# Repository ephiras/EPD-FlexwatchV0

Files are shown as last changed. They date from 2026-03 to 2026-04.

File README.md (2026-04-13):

# The Inkwell Watch (A curved eink watch)

previously the flexwatch.

A simple, low stress smartwatch built around a 2.9 inch e ink display, a custom PCB, and a lot of improvised problem solving. This repository contains the Arduino code and the Eagle hardware files for the current working version.

The goal is a comfortable watch that is easy on the eyes, lasts a long time on a charge, and does not behave like a tiny phone.


---

## What is in this repository

### code
Arduino sketches for the current version.  
Bluetooth and microphone support are not implemented yet, but the hardware is ready.

### hardware
Eagle schematic and PCB layout for the custom flex board used in the build.
tmp_00848f6a-d5dd-4d53-946b-520c7fa0a136
---

## Current features

- 2.9 inch e ink display  
- Seeed Studio nRF52840 Sense  
- IMU support  
- Basic watch interface  
- Low power modes  
- Custom flex PCB  
- Ruler based rigid frame  

---

## Planned features

- Bluetooth  
- Microphone  
- GPS (new layout needed)  
- Heart rate sensor  
- UV sensor  
- Rigid flex PCB  
- Improved sleep modes  
- RTC backup battery  

---

# The Zephyr Migration
I’ve started migrating the firmware for the e‑ink smartwatch from the Arduino environment to Zephyr RTOS. This is a significant step forward for the project and sets up a much more robust foundation for future development.

## Why the migration
- Better power management: Zephyr gives fine‑grained control over sleep states, peripherals, and scheduling, which is essential for a low‑power wearable running on a small battery.
- Native nRF52840 support: Zephyr’s Nordic integration is far deeper than Arduino’s, with first‑class drivers, BLE stack support, and stable APIs.
- Modular architecture: The RTOS structure makes it easier to separate display handling, sensors, BLE, and UI logic into clean, maintainable modules.
- Scalability: As the watch grows beyond a simple prototype, Arduino’s abstractions become limiting. Zephyr provides a long‑term path for more complex features.

---

## Notes
This is a work in progress.  
The hardware files match the version shown in the Instructables build.  https://www.instructables.com/Building-a-Lightweight-Curved-EInk-Smartwatch/
Expect changes as the design evolves.

if you want to, please join the discord
https://discord.gg/58VtJPHzf

## License

MIT License.  
Feel free to use, modify, and build on this project.

Please reach out or credit me if you do use any of my schematics/ pcb layout. I would really appreciate it! would also be great to see what you come up with.

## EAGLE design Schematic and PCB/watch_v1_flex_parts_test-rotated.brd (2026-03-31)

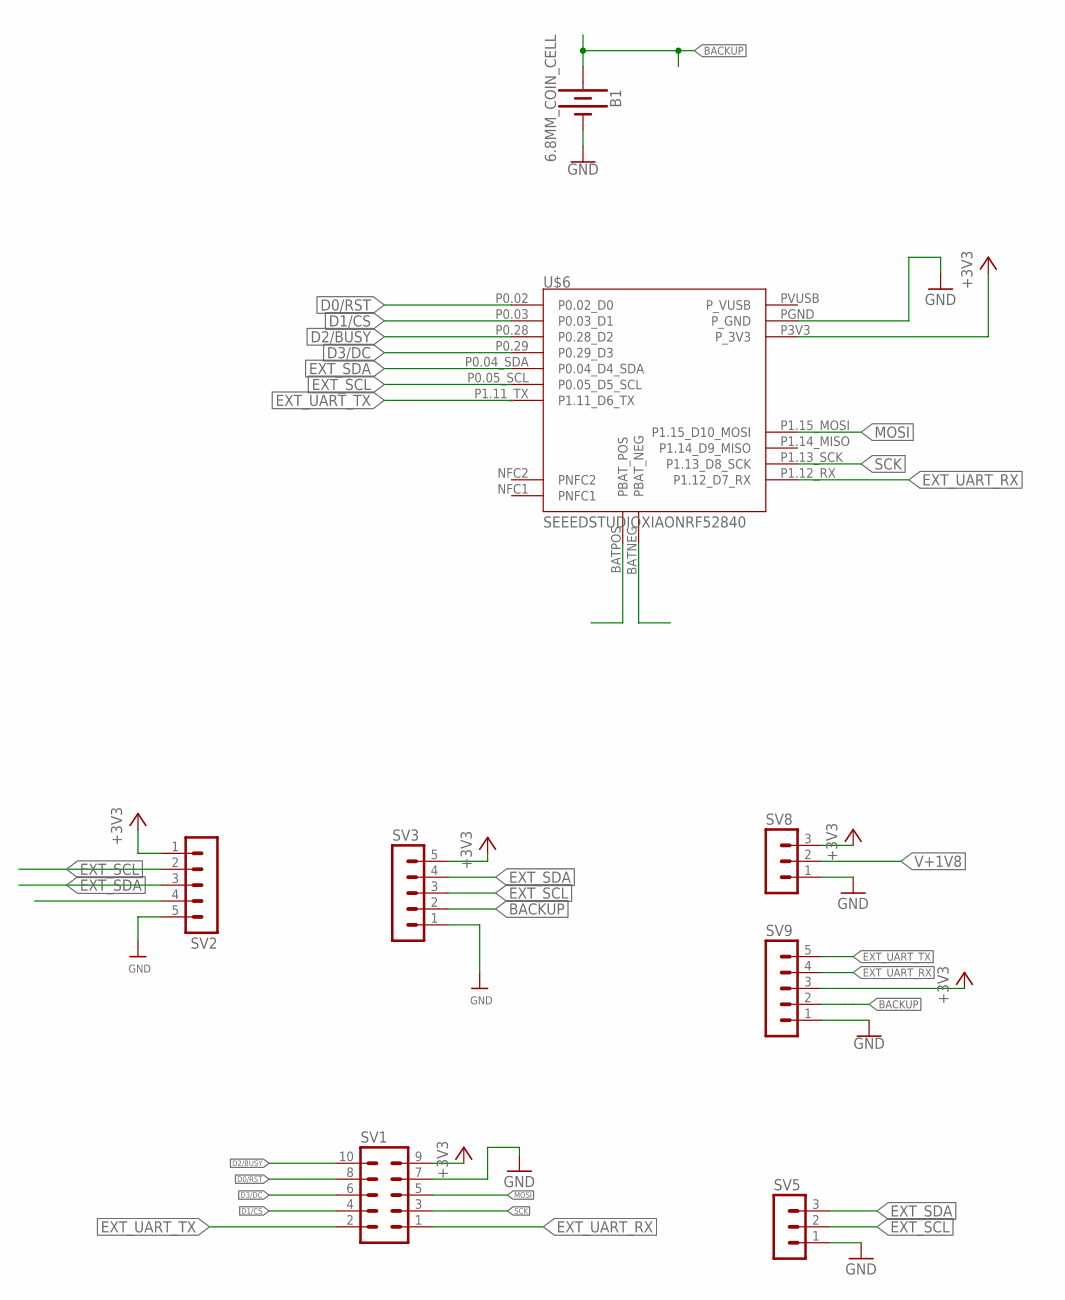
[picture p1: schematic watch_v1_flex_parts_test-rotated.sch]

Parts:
B1: 6.8MM_COIN_CELL; ML414H_IV01E
SV1: MA05-2
SV2, SV3, SV9: MA05-1
SV5, SV8: MA03-1
U$6: SEEEDSTUDIOXIAONRF52840

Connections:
+3V3: SV1.9, SV2.1, SV3.5, SV8.3, SV9.3, U$6.P3V3 (P_3V3)
BACKUP: B1.+, SV3.2, SV9.2
D0/RST: SV1.8, U$6.P0.02 (P0.02_D0)
D1/CS: SV1.4, U$6.P0.03 (P0.03_D1)
D2/BUSY: SV1.10, U$6.P0.28 (P0.28_D2)
D3/DC: SV1.6, U$6.P0.29 (P0.29_D3)
EXT_SCL: SV2.2, SV3.3, SV5.2, U$6.P0.05_SCL (P0.05_D5_SCL)
EXT_SDA: SV2.3, SV3.4, SV5.3, U$6.P0.04_SDA (P0.04_D4_SDA)
EXT_UART_RX: SV1.1, SV9.4, U$6.P1.12_RX (P1.12_D7_RX)
EXT_UART_TX: SV1.2, SV9.5, U$6.P1.11_TX (P1.11_D6_TX)
GND: B1.-, SV1.7, SV2.5, SV3.1, SV5.1, SV8.1, SV9.1, U$6.PGND (P_GND)
MOSI: SV1.5, U$6.P1.15_MOSI (P1.15_D10_MOSI)
SCK: SV1.3, U$6.P1.13_SCK (P1.13_D8_SCK)
V+1V8: SV8.2

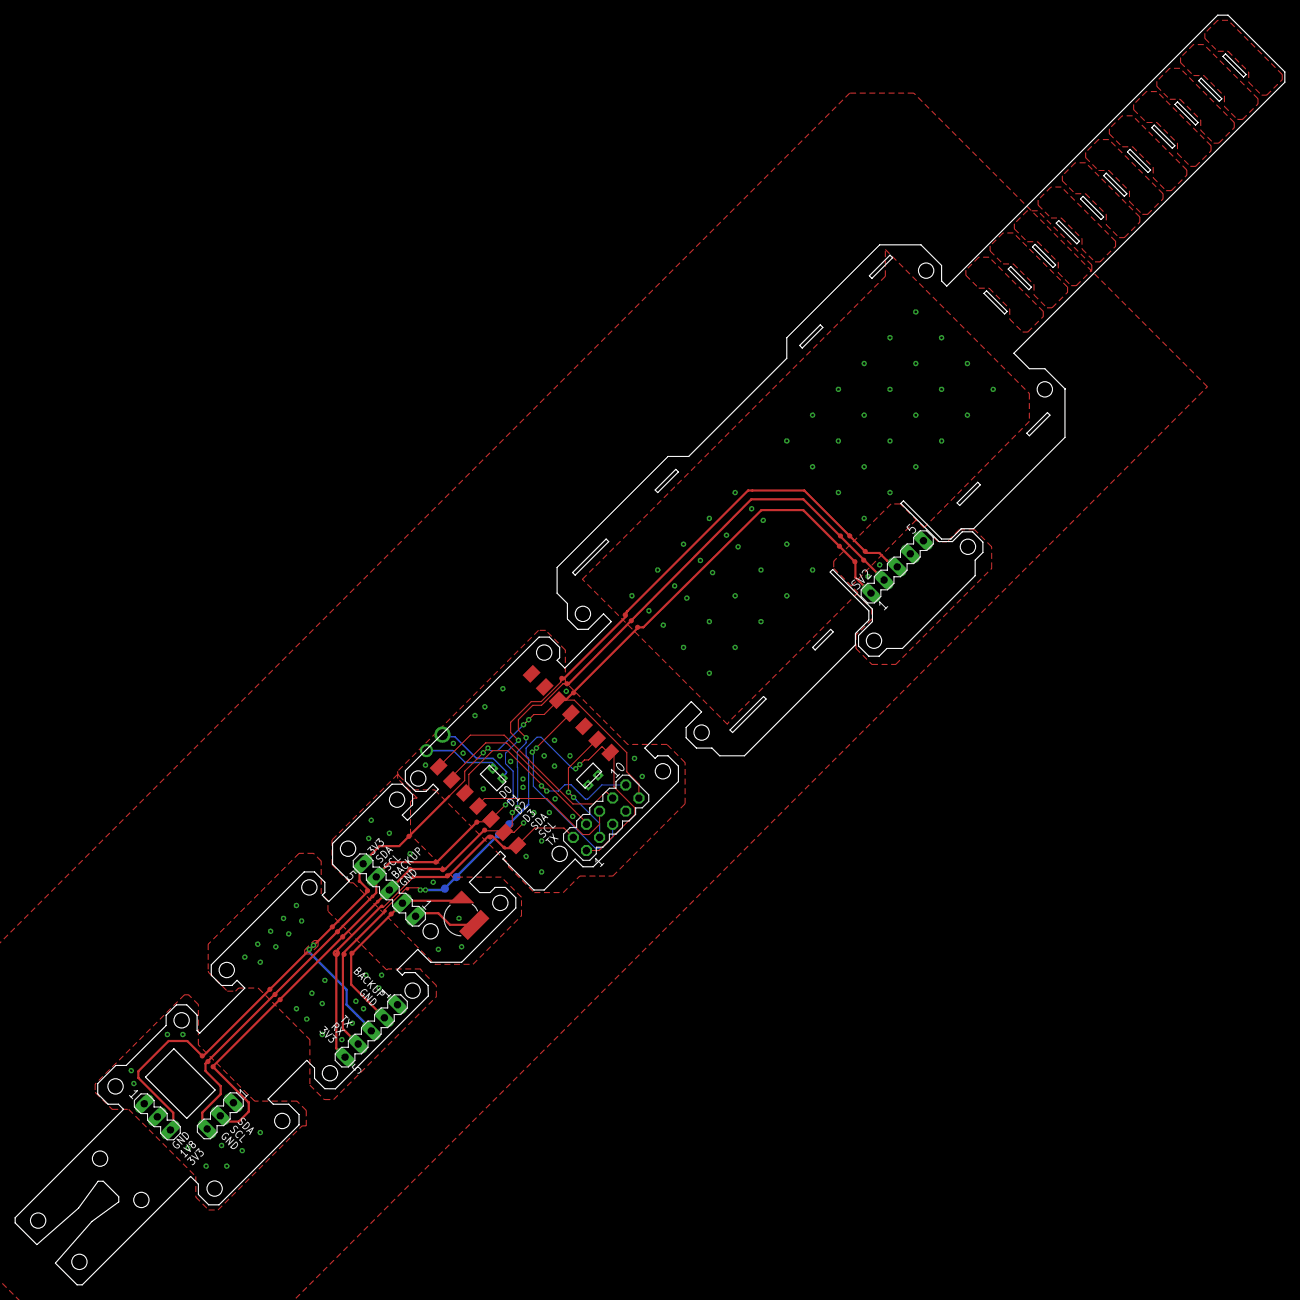
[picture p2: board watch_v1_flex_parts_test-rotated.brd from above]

Board: 2 copper layers, 173.9 x 173.9 mm, 8 parts (0 on the bottom side), 13 nets.

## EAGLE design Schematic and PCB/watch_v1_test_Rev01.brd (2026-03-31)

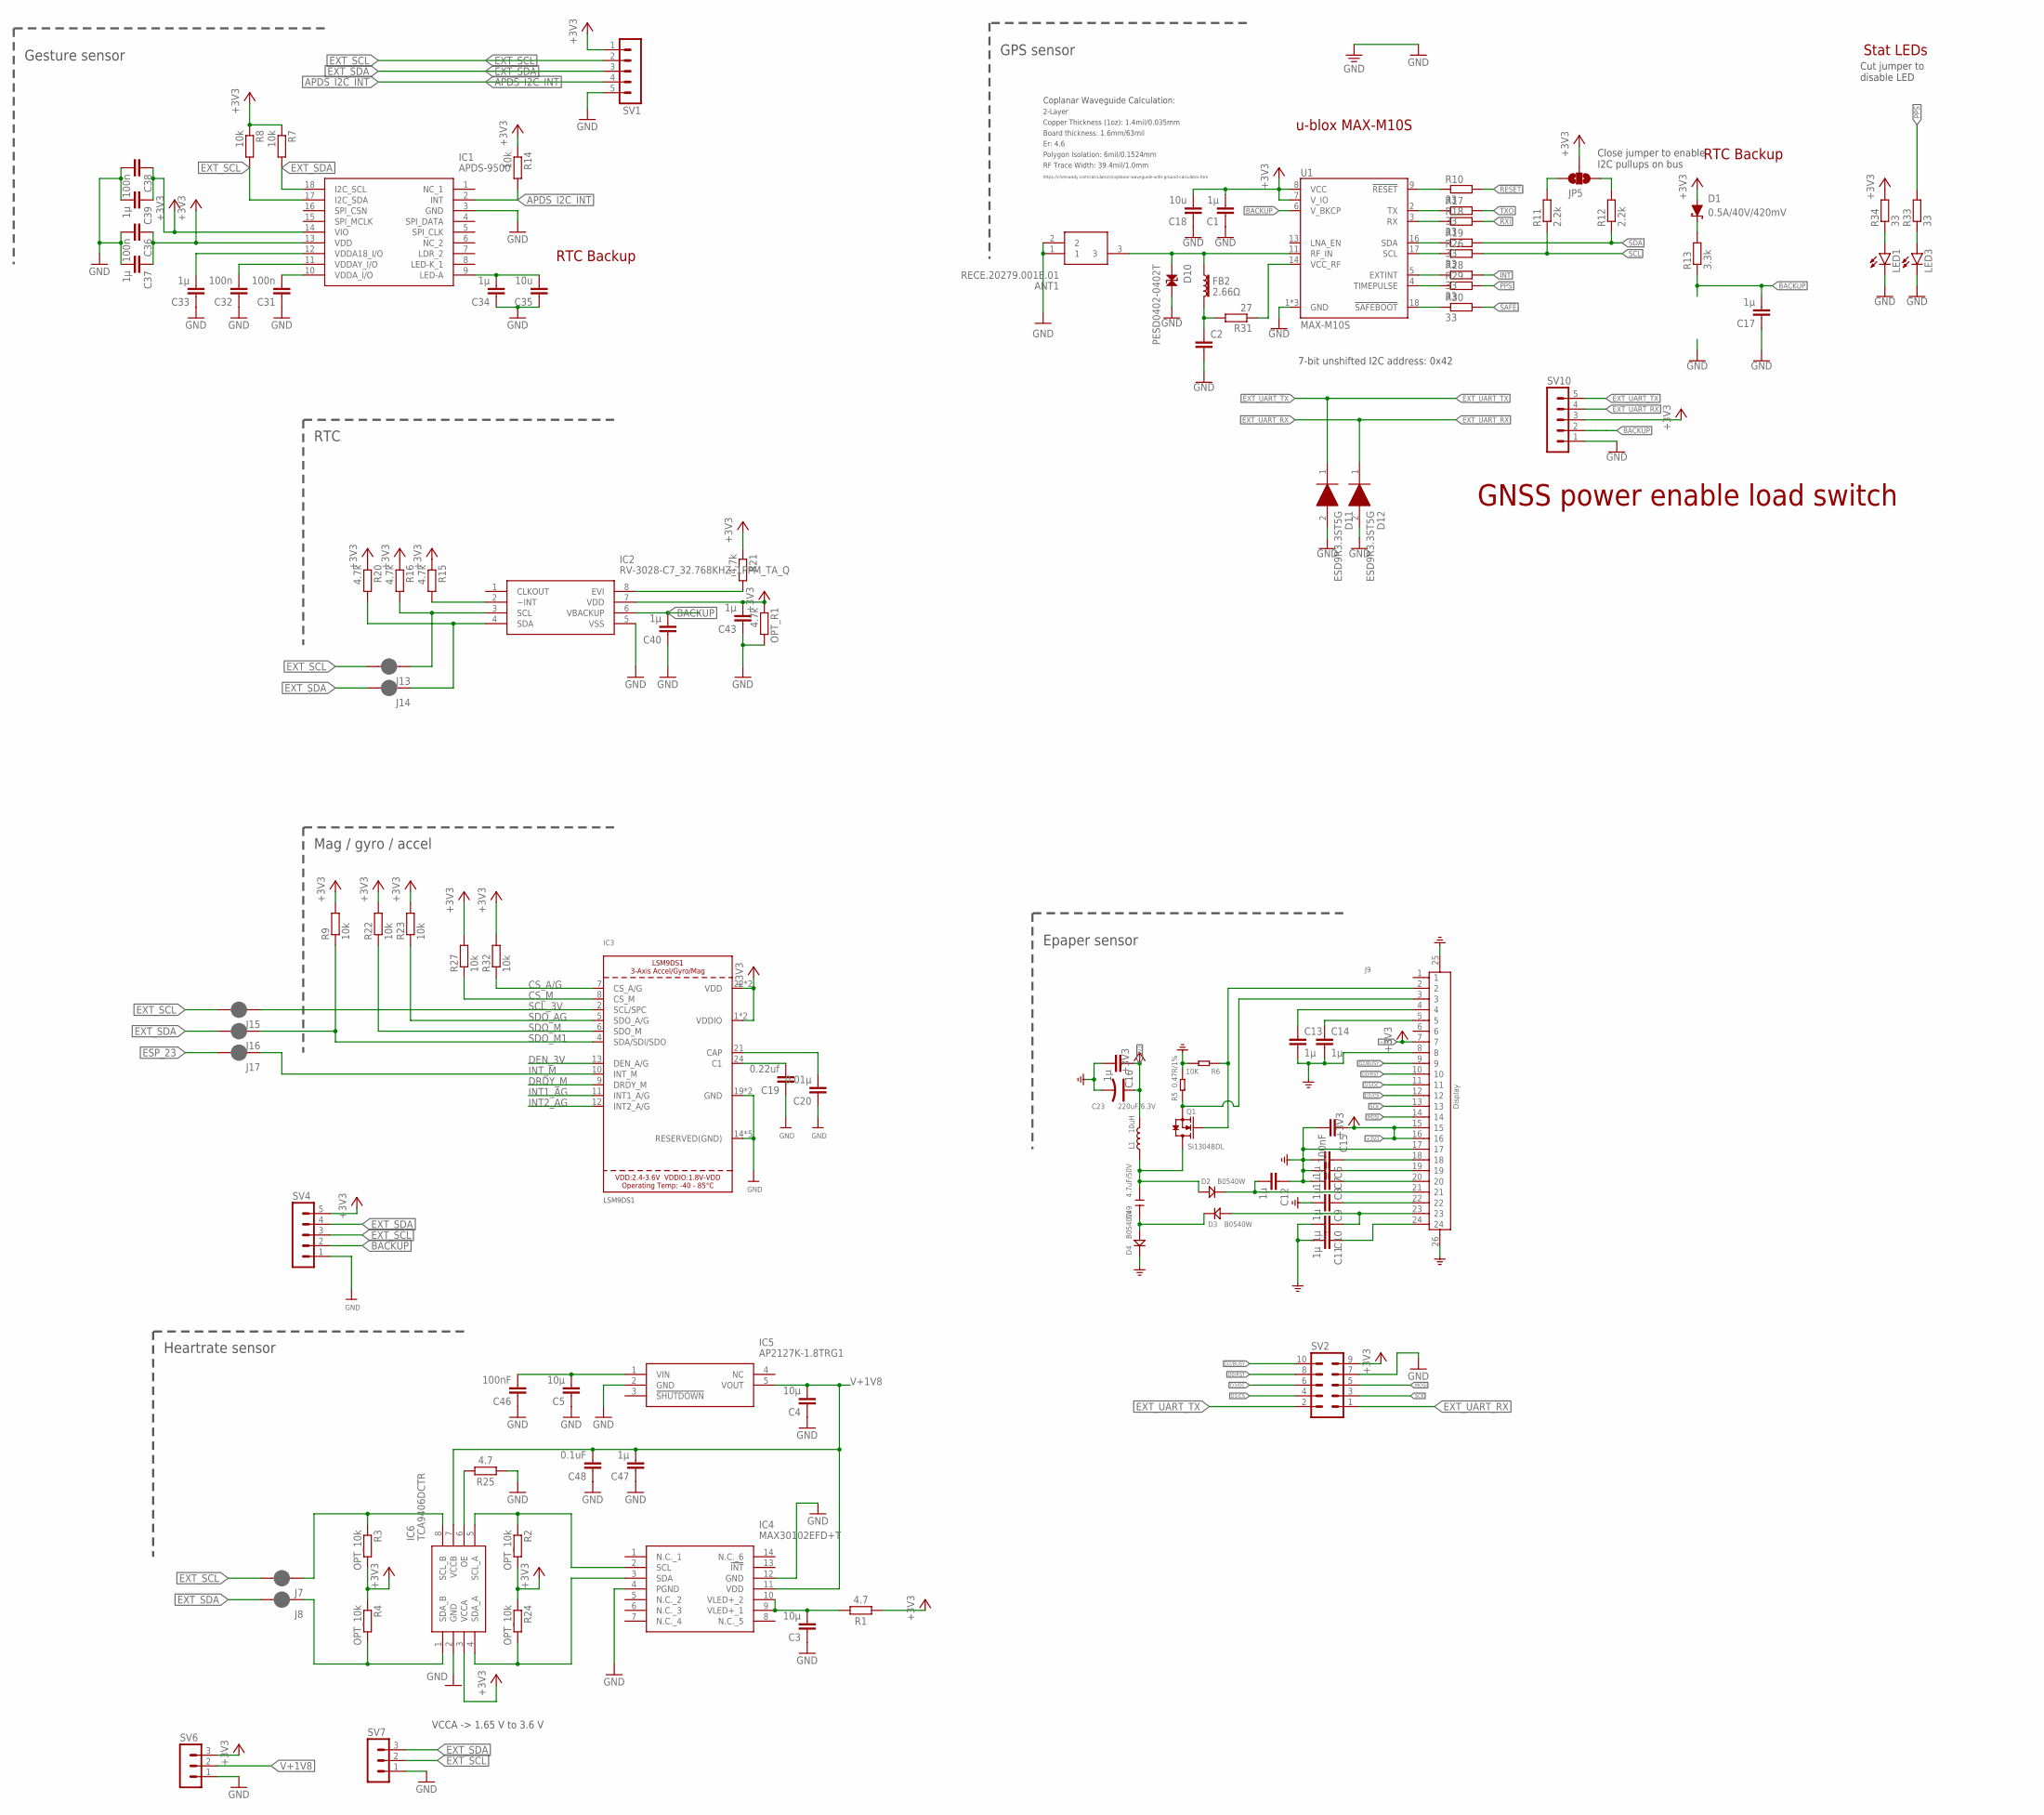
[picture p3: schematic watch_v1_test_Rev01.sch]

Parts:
ANT1: RECE.20279.001E.01
C1, C6, C7, C8, C9, C10, C11, C12, C13, C14, C16, C17, C33, C34, C37, C39, C40, C43, C47: 1µ; C0402_S
C2: 47pF; 0402-TIGHT
C3, C4, C5: 10µ; C0402_S
C15, C46: 100nF; C0402_S
C18, C35: 10u; C0402_S
C19: 0.22uf; C0402_S
C20: 0.01µ; C0402_S
C23: 220uF/6.3V; AVX-B
C31, C32, C36, C38: 100n; C0402_S
C48: 0.1uF; C0402_S
C49: 4.7uF/50V; C1206
D1: 0.5A/40V/420mV; SOD-323
D2, D3, D4: B0540W; SOD-323
D10: PESD0402-0402T; 0402-TIGHT
D11, D12: ESD9R3.3ST5G; SODFL1006X40N
FB2: 2.66Ω; 0402-TIGHT
IC1: APDS-9500; APDS9500
IC2: RV-3028-C7_32.768KHZ_1PPM_TA_Q; RV3028C732768KHZ1PPMTAQC
IC3: LSM9DS1; LGA24_3.5X3.1MM
IC4: MAX30102EFD+T; MAX30102EFDT
IC5: AP2127K-1.8TRG1; SOT95P282X145-5N
IC6: TCA9406DCTR; SOP65P400X130-8N
J7, J8, J13, J14, J15, J16, J17: SMT_JUMPER_2_NC_PASTE; JUMPER_SMALL
J9: Display; FPCB24-SMD-0.5-17.6X5.0X2MM
JP5: JUMPER-SMT_3_NO_SILK; SMT-JUMPER_3_NO_SILK
L1: 10uH; L0420
LED1, LED3: LEDSML0603; SML0603; MPN 150060GS84000
OPT_R1: 4.7k; R0402
Q1: Si1304BDL; SOT-323
R1, R25: 4.7; RESC1608X60
R2, R3, R4, R24: OPT_10k; R0402
R5: 0.47R/1%; R0603
R6: 10K; R0603
R7, R8, R9, R14, R22, R23, R27, R32: 10k; R0402
R10, R17, R18, R19, R26, R28, R29, R30, R33, R34: 33; R0402
R11, R12: 2.2k; R0402
R13: 3.3k; R0402
R15, R16, R20, R21: 4.7k; R0402
R31: 27; R0402
SV1, SV4, SV10: MA05-1
SV2: MA05-2
SV6, SV7: MA03-1
U1: MAX-M10S

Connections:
!RESET: R10.2
!SAFE: R30.2
+3V3: C1.P$2 (2), C15.P$1 (1), C16.P$1 (1), C18.P$2 (2), C23.+, C36.P$1 (1), C37.P$1 (1), C38.P$1 (1), C39.P$1 (1), C43.P$2 (2), D1.A, IC1.13 (VDD), IC1.14 (VIO), IC2.7 (VDD), IC3.1 (VDDIO), IC3.3 (VDDIO), IC3.22 (VDD), IC3.23 (VDD), IC6.3 (VCCA), J9.7, J9.15, J9.16, JP5.2, L1.2, OPT_R1.1, R1.1, R2.2, R3.2, R4.1, R7.1, R8.1, R9.2, R14.1, R15.1, R16.1, R20.1, R21.1, R22.2, R23.2, R24.1, R27.2, R32.2, R34.2, SV1.1, SV2.9, SV4.5, SV6.3, SV10.3, U1.7 (V_IO), U1.8 (VCC)
ANT_VCC: C2.1, FB2.2, R31.2
APDS_I2C_INT: IC1.2 (INT), R14.2, SV1.4
BACKUP: C17.P$2 (2), C40.P$2 (2), IC2.6 (VBACKUP), R13.1, SV4.2, SV10.2, U1.6 (V_BKCP)
C1: C19.P$2 (2), IC3.24 (C1)
CAP: C20.P$2 (2), IC3.21 (CAP)
CS_A/G: IC3.7 (CS_A/G), R32.1
CS_M: IC3.8 (CS_M), R27.1
D0/RST: J9.10, SV2.8
D1/CS: J9.12, SV2.4
D2/BUSY: J9.9, SV2.10
D3/DC: J9.11, SV2.6
DEN_3V: IC3.13 (DEN_A/G)
DRDY_M: IC3.9 (DRDY_M)
ESP_23: J17.P$2 (2)
EXTINT_LV: R28.1, U1.5 (EXTINT)
EXT_SCL: IC1.17 (I2C_SDA), J7.P$2 (2), J13.P$2 (2), J15.P$2 (2), R8.2, SV1.2, SV4.3, SV7.2
EXT_SDA: IC1.18 (I2C_SCL), J8.P$2 (2), J14.P$2 (2), J16.P$2 (2), R7.2, SV1.3, SV4.4, SV7.3
EXT_UART_RX: D12.1 (K), SV2.1, SV10.4
EXT_UART_TX: D11.1 (K), SV2.2, SV10.5
GDR: J9.2, Q1.1 (G), R6.1
GND: ANT1.1, ANT1.2, C1.P$1 (1), C2.2, C3.P$1 (1), C4.P$1 (1), C5.P$1 (1), C6.P$2 (2), C7.P$2 (2), C8.P$2 (2), C9.P$2 (2), C10.P$2 (2), C11.P$2 (2), C12.P$1 (1), C13.P$2 (2), C14.P$2 (2), C15.P$2 (2), C16.P$2 (2), C17.P$1 (1), C18.P$1 (1), C19.P$1 (1), C20.P$1 (1), C23.-, C31.P$1 (1), C32.P$1 (1), C33.P$1 (1), C34.P$1 (1), C35.P$1 (1), C36.P$2 (2), C37.P$2 (2), C38.P$2 (2), C39.P$2 (2), C40.P$1 (1), C43.P$1 (1), C46.P$1 (1), C47.P$1 (1), C48.P$1 (1), D4.-, D10.2, D11.2 (A), D12.2 (A), IC1.3 (GND), IC2.5 (VSS), IC3.14 (RESERVED(GND)), IC3.15 (RESERVED(GND)), IC3.16 (RESERVED(GND)), IC3.17 (RESERVED(GND)), IC3.18 (RESERVED(GND)), IC3.19 (GND), IC3.20 (GND), IC4.4 (PGND), IC4.12 (GND), IC5.2 (GND), IC6.2 (GND), J9.8, J9.17, J9.25 (P1), J9.26 (P2), LED1.C, LED3.C, OPT_R1.2, R5.2, R6.2, R25.1, SV1.5, SV2.7, SV4.1, SV6.1, SV7.1, SV10.1, U1.1 (GND), U1.10 (GND), U1.12 (GND)
GPS_RF: ANT1.3, D10.1, FB2.1, U1.11 (RF_IN)
INT: R28.2
INT1_AG: IC3.11 (INT1_A/G)
INT2_AG: IC3.12 (INT2_A/G)
INT_M: IC3.10 (INT_M), J17.P$1 (1)
MOSI: J9.14, SV2.5
unnamed: C5.P$2 (2), C46.P$2 (2), IC5.1 (VIN)
unnamed: IC4.2 (SCL), IC6.5 (SCL_A), R2.1
unnamed: IC4.3 (SDA), IC6.4 (SDA_A), R24.2
unnamed: C31.P$2 (2), IC1.10 (VDDA_I/O)
unnamed: IC6.8 (SCL_B), J7.P$1 (1), R3.1
unnamed: IC6.1 (SDA_B), J8.P$1 (1), R4.2
unnamed: LED3.A, R33.1
unnamed: C32.P$2 (2), IC1.11 (VDDAY_I/O)
unnamed: C33.P$2 (2), IC1.12 (VDDA18_I/O)
unnamed: C34.P$2 (2), C35.P$2 (2), IC1.9 (LED-A)
unnamed: LED1.A, R34.1
unnamed: IC2.4 (SDA), J14.P$1 (1), R20.2
unnamed: C3.P$2 (2), IC4.9 (VLED+_1), IC4.10 (VLED+_2), R1.2
unnamed: IC2.3 (SCL), J13.P$1 (1), R16.2
unnamed: IC2.2 (~INT), R15.2
unnamed: JP5.1, R12.2
unnamed: JP5.3, R11.2
unnamed: D1.C, R13.2
unnamed: C6.P$1 (1), J9.18
unnamed: C7.P$1 (1), J9.19
unnamed: C8.P$1 (1), J9.20
unnamed: IC6.6 (OE), R25.2
unnamed: IC2.8 (EVI), R21.2
unnamed: C12.P$2 (2), D2.-, J9.21
unnamed: C9.P$1 (1), J9.22
unnamed: C10.P$1 (1), D3.+, J9.23
unnamed: C49.1, D3.-, D4.+
unnamed: C49.2, D2.+, L1.1, Q1.3 (D)
unnamed: C13.P$1 (1), J9.4
PPS: R29.2, R33.2
PPS_LV: R29.1, U1.4 (TIMEPULSE)
RESE: J9.3, Q1.2 (S), R5.1
RST_LV: R10.1, U1.9 (!RESET!)
RXI: R18.2
RXLV: R18.1, U1.3 (RX)
SAFE_LV: R30.1, U1.18 (!SAFEBOOT!)
SCK: J9.13, SV2.3
SCL: R11.1, R26.2
SCL_3V: IC3.2 (SCL/SPC), J15.P$1 (1)
SCL_LV: R26.1, U1.17 (SCL)
SDA: R12.1, R19.2
SDA_LV: R19.1, U1.16 (SDA)
SDO_AG: IC3.5 (SDO_A/G), R23.1
SDO_M: IC3.6 (SDO_M), R22.1
SDO_M1: IC3.4 (SDA/SDI/SDO), J16.P$1 (1), R9.1
TXLV: R17.1, U1.2 (TX)
TXO: R17.2
V+1V8: C4.P$2 (2), C47.P$2 (2), C48.P$2 (2), IC4.11 (VDD), IC5.5 (VOUT), IC6.7 (VCCB), SV6.2
VCC_RF: R31.1, U1.14 (VCC_RF)
VCOM: C11.P$1 (1), J9.24
VGH: C14.P$1 (1), J9.5

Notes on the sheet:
VCCA -> 1.65 V to 3.6 V
Heartrate sensor
Mag / gyro / accel
RTC
GNSS power enable load switch
GPS sensor
Epaper sensor
7-bit unshifted I2C address: 0x42
u-blox MAX-M10S
RTC Backup
Close jumper to enable I2C pullups on bus
Coplanar Waveguide Calculation:
Board thickness: 1.6mm/63mil
Er: 4.6
Copper Thickness (1oz): 1.4mil/0.035mm
RF Trace Width: 39.4mil/1.0mm
Polygon Isolation: 6mil/0.1524mm
2-Layer
https://chemandy.com/calculators/coplanar-waveguide-with-ground-calculator.htm
Stat LEDs
Cut jumper to disable LED
Gesture sensor

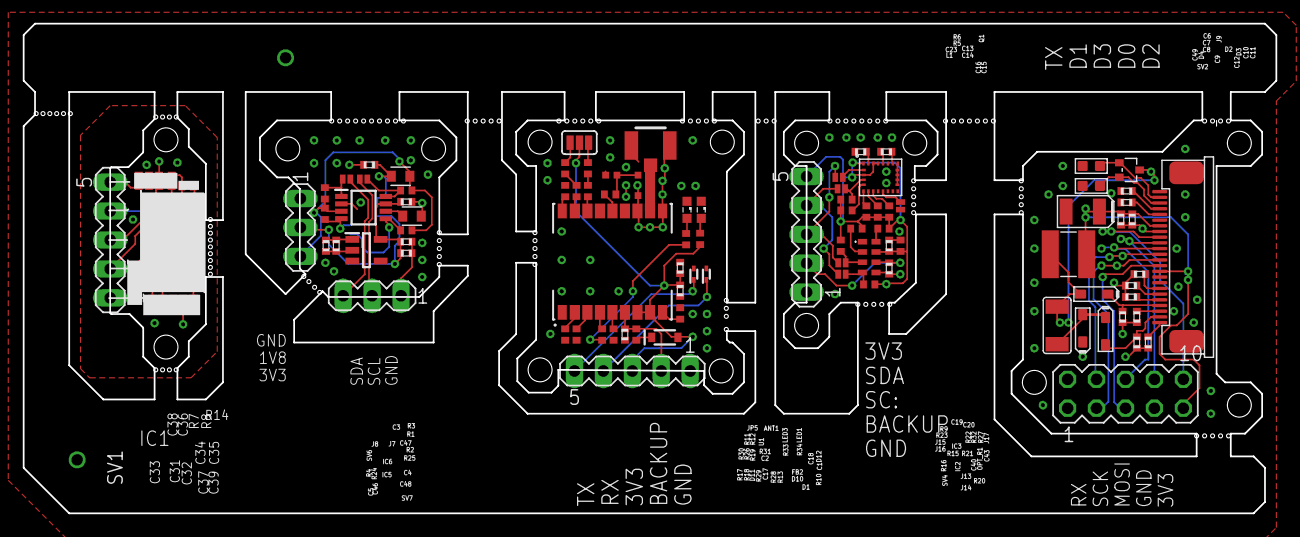
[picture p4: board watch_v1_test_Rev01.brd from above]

Board: 2 copper layers, 110.0 x 43.0 mm, 106 parts (1 on the bottom side), 71 nets.

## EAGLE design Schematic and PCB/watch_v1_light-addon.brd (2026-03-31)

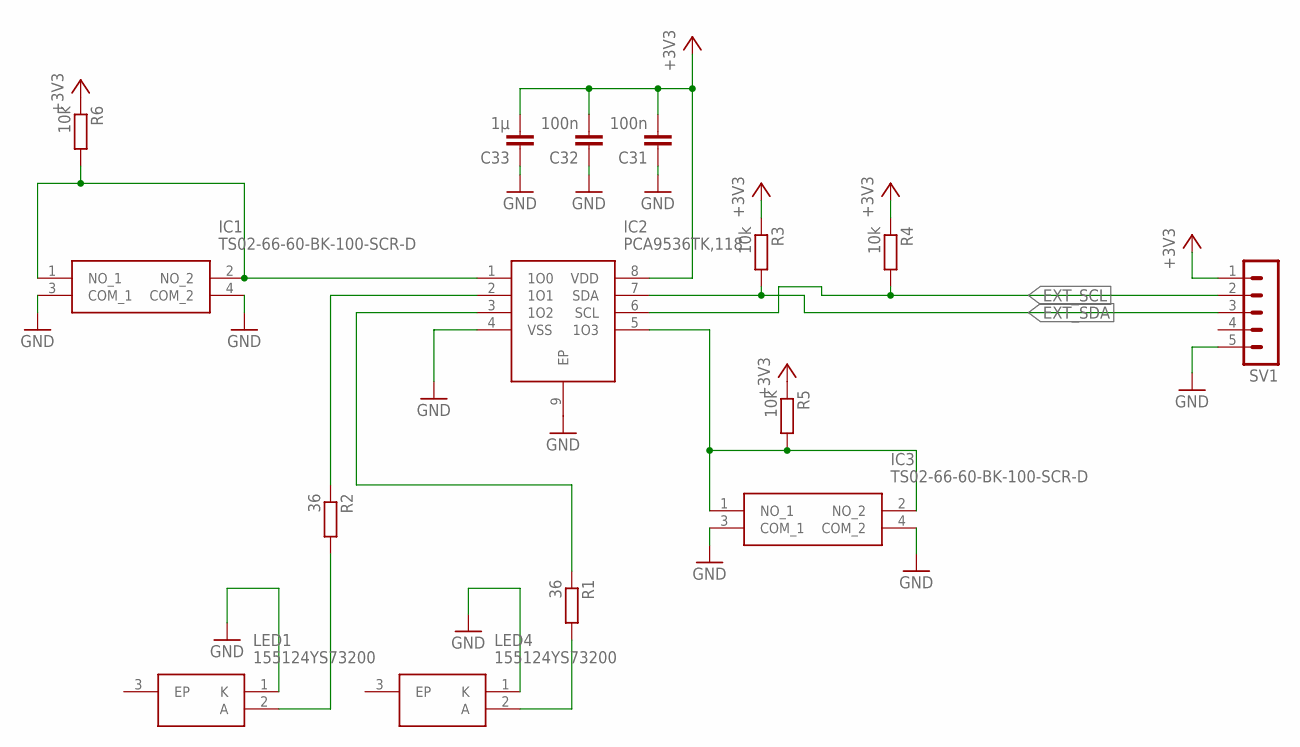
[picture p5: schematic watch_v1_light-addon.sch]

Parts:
C31, C32: 100n; C0402_S
C33: 1µ; C0402_S
IC1, IC3: TS02-66-60-BK-100-SCR-D; TS026660BK100SCRD
IC2: PCA9536TK,118; SON50P300X300X100-9N
LED1, LED4: 155124YS73200
R1, R2: 36; R0402
R3, R4, R5, R6: 10k; R0402
SV1: MA05-1

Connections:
+3V3: C31.P$2 (2), C32.P$2 (2), C33.P$2 (2), IC2.8 (VDD), R3.1, R4.1, R5.1, R6.1, SV1.1
EXT_SCL: IC2.6 (SCL), R4.2, SV1.2
EXT_SDA: IC2.7 (SDA), R3.2, SV1.3
GND: C31.P$1 (1), C32.P$1 (1), C33.P$1 (1), IC1.3 (COM_1), IC1.4 (COM_2), IC2.4 (VSS), IC2.9 (EP), IC3.3 (COM_1), IC3.4 (COM_2), LED1.1 (K), LED4.1 (K), SV1.5
unnamed: IC1.1 (NO_1), IC1.2 (NO_2), IC2.1 (1O0), R6.2
unnamed: IC2.2 (1O1), R2.1
unnamed: LED4.2 (A), R1.2
unnamed: LED1.2 (A), R2.2
unnamed: IC2.3 (1O2), R1.1
unnamed: IC2.5 (1O3), IC3.1 (NO_1), IC3.2 (NO_2), R5.2

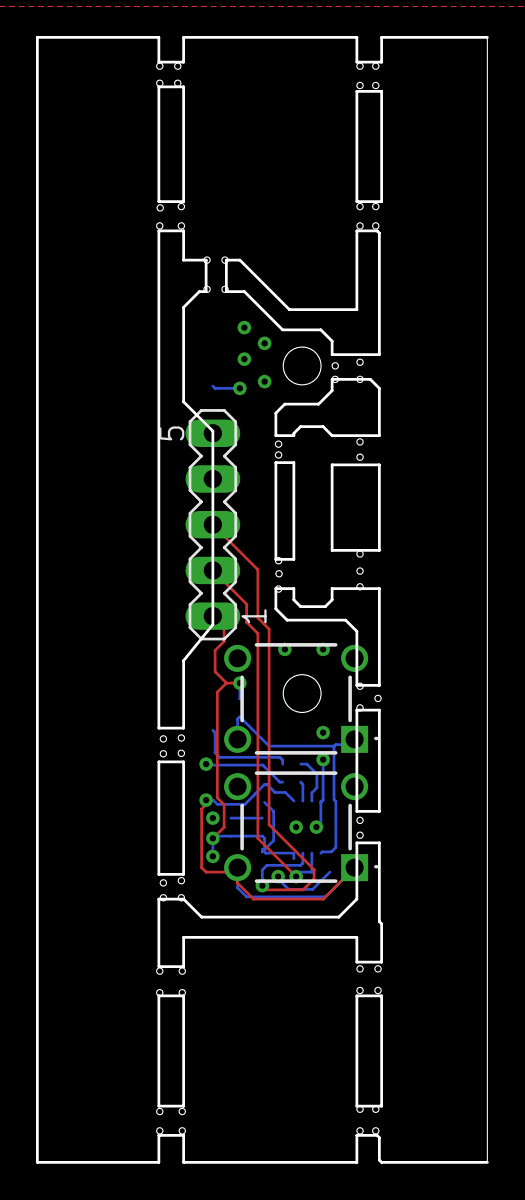
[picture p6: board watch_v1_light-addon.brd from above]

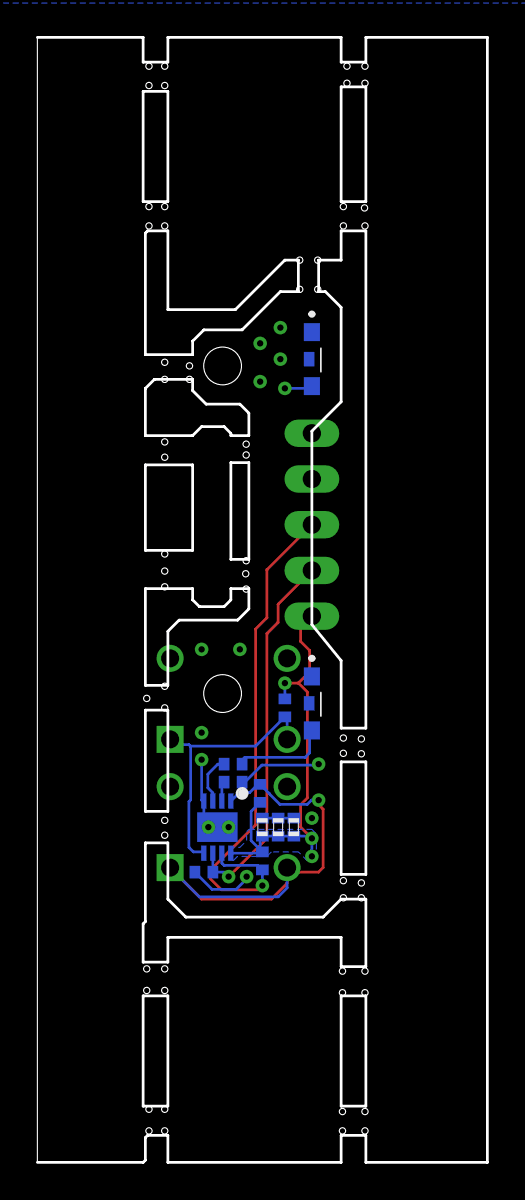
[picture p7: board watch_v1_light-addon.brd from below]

Board: 4 copper layers, 25.0 x 62.5 mm, 15 parts (12 on the bottom side), 10 nets.

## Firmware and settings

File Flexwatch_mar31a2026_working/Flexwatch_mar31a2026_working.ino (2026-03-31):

#include <Wire.h>
#include <GxEPD2_BW.h>
#include <Fonts/FreeMonoBold9pt7b.h>
#include <Fonts/FreeMonoBold18pt7b.h>
#include <LSM6DS3.h>
#include <RV3028C7.h>

// =====================================================
// Pin mapping for Seeed Studio XIAO nRF52840 Sense
// =====================================================
#define EPD_CS   D1
#define EPD_DC   D3
#define EPD_RST  D0
#define EPD_BUSY D2

// Battery measurement pins
#define BAT_PIN PIN_VBAT
#define BAT_PIN_ENABLE 14

// ADC conversion constants for battery voltage
#define VBAT_MV_PER_LSB   (0.73242188F)   // 3.0V reference, 12 bit ADC
#define VBAT_DIVIDER      (0.66225165F)   // Voltage divider ratio
#define VBAT_DIVIDER_COMP (0.001F)        // Compensation factor

#define REAL_VBAT_MV_PER_LSB (VBAT_DIVIDER_COMP * VBAT_MV_PER_LSB)

// Battery state of charge lookup table (rough approximation)
const uint8_t socTable[11] = {
  0, 10, 20, 30, 40, 50, 60, 70, 80, 90, 100
};

// Approximate LiPo voltage curve for 0 to 100 percent
const float vTable[11] = {
  3.20, 3.35, 3.50, 3.60, 3.68, 3.73, 3.77, 3.80, 3.85, 3.95, 4.20
};

// ADC reference values
const float ADC_REF = 3.0;
const int ADC_MAX = 4095;
const float DIVIDER_RATIO = 3.0;

// =====================================================
// E paper display instance (2.9 inch Waveshare panel)
// =====================================================
GxEPD2_BW<GxEPD2_290_I6FD, GxEPD2_290_I6FD::HEIGHT> display(
  GxEPD2_290_I6FD(EPD_CS, EPD_DC, EPD_RST, EPD_BUSY)
);

// RTC and IMU instances
RV3028C7 rtc;
LSM6DS3 imu(I2C_MODE, 0x6A);

// Time tracking
int lastMinute = -1;
unsigned long lastMotionMillis = 0;
bool screenCleared = false;

// =====================================================
// Convert compile time into ISO 8601 format
// Used to set RTC on first flash
// =====================================================
String compileTimeISO8601() {
  const char* months = "JanFebMarAprMayJunJulAugSepOctNovDec";
  char monthStr[4];
  int day, year;

  // Parse __DATE__
  sscanf(__DATE__, "%3s %d %d", monthStr, &day, &year);
  int month = (strstr(months, monthStr) - months) / 3 + 1;

  // Parse __TIME__
  int hour, minute, second;
  sscanf(__TIME__, "%d:%d:%d", &hour, &minute, &second);

  // Build ISO string
  char isoStr[25];
  snprintf(isoStr, sizeof(isoStr), "%04d-%02d-%02dT%02d:%02d:%02d",
           year, month, day, hour, minute, second);

  return String(isoStr);
}

// =====================================================
// Read battery voltage and return "(XX%)" string
// =====================================================
String getBatteryVoltage() {
  // Use 3.0V internal reference
  analogReference(AR_INTERNAL_3_0);
  analogReadResolution(12);
  delay(1);

  int raw = analogRead(BAT_PIN);

  // Restore defaults
  analogReference(AR_DEFAULT);
  analogReadResolution(10);

  float adcVoltage = raw * REAL_VBAT_MV_PER_LSB;
  float batteryVoltage = adcVoltage * DIVIDER_RATIO;
  int percent = batteryPercent(batteryVoltage);

  // Build percentage string
  String result = "(";
  result += String(percent);
  result += "%)";

  Serial.printf("[BAT] ADCVolt=%.3f batVolt=%.3f percent=%.3f\n",
                adcVoltage, batteryVoltage, percent);

  return result;
}

// =====================================================
// Convert battery voltage to approximate percentage
// Using linear interpolation between vTable entries
// =====================================================
int batteryPercent(float v) {
  if (v <= vTable[0]) return socTable[0];
  if (v >= vTable[10]) return socTable[10];

  int i;
  for (i = 0; i < 10; i++) {
    if (v < vTable[i + 1]) break;
  }

  float v0 = vTable[i];
  float v1 = vTable[i + 1];
  int s0 = socTable[i];
  int s1 = socTable[i + 1];

  float t = (v - v0) / (v1 - v0);
  float soc = s0 + t * (s1 - s0);

  if (soc < 0.0f) soc = 0.0f;
  if (soc > 100.0f) soc = 100.0f;

  return (int)(soc + 0.5f);
}

// =====================================================
// Setup
// =====================================================
void setup() {
  Serial.begin(115200);
  while (!Serial) {}

  Serial.println("=== E Paper Watch (Compile Time RTC Set) ===");

  Wire.begin();

  // Battery measurement setup
  pinMode(BAT_PIN_ENABLE, OUTPUT);
  digitalWrite(BAT_PIN_ENABLE, LOW);
  pinMode(BAT_PIN, INPUT);

  // Init e paper display
  Serial.println("[INIT] E paper...");
  display.init(4000000);
  display.setRotation(3);
  display.setFullWindow();
  Serial.println("[OK] E paper ready");

  // Init RTC
  Serial.println("[INIT] RTC...");
  if (!rtc.begin()) {
    Serial.println("[ERROR] Could not find RV3028C7 RTC");
    while (1);
  }
  Serial.println("[OK] RTC ready");

  // Set RTC to compile time (only needed once)
  String dateTime = compileTimeISO8601();
  Serial.print("[SET] Setting RTC to compile time: ");
  Serial.println(dateTime);
  rtc.setDateTimeFromISO8601(dateTime);
  rtc.synchronize();
  // COMMENT OUT ABOVE AFTER FIRST FLASH

  // Clear ghosting on e paper
  display.fillScreen(GxEPD_BLACK);
  display.fillScreen(GxEPD_BLACK);
  display.fillScreen(GxEPD_WHITE);
  display.fillScreen(GxEPD_BLACK);

  // Init IMU
  Serial.println("[INIT] IMU...");
  if (imu.begin() != 0) {
    Serial.println("[ERROR] Could not find LSM6DS3 IMU");
    while (1);
  }
  Serial.println("[OK] IMU ready");

  updateDisplay();
  lastMotionMillis = millis();
}

// =====================================================
// Main loop
// =====================================================
void loop() {
  // Read accelerometer
  float ax = imu.readFloatAccelX();
  float ay = imu.readFloatAccelY();
  float az = imu.readFloatAccelZ();
  float magnitude = sqrt(ax * ax + ay * ay + az * az);

  // Read time from RTC
  String nowstr = rtc.getCurrentDateTime();
  int minuteNow = nowstr.substring(14, 16).toInt();

  // Detect wrist movement
  if (magnitude > 1.2) {
    Serial.printf("[IMU] X=%.3f Y=%.3f Z=%.3f Mag=%.3f\n",
                  ax, ay, az, magnitude);
    lastMotionMillis = millis();
    screenCleared = false;
    digitalWrite(LED_PWR, LOW);
  }

  // Update display once per minute
  if (minuteNow != lastMinute && !screenCleared) {
    Serial.println("[TRIGGER] Updating display...");
    lastMinute = minuteNow;
    updateDisplay();
  } else {
    // Clear screen after 5 minutes of no movement
    if (!screenCleared && (millis() - lastMotionMillis > 300000)) {
      Serial.println("[TIMEOUT] No motion for 300s, clearing screen...");
      display.firstPage();
      do {
        display.fillScreen(GxEPD_WHITE);
      } while (display.nextPage());
      screenCleared = true;
    }
  }

  delay(500);
}

// =====================================================
// Draw time, date, and battery on e paper
// =====================================================
void updateDisplay() {
  String nowstr = rtc.getCurrentDateTime();

  int year    = nowstr.substring(0, 4).toInt();
  int month   = nowstr.substring(5, 7).toInt();
  int day     = nowstr.substring(8, 10).toInt();
  int hours   = nowstr.substring(11, 13).toInt();
  int minutes = nowstr.substring(14, 16).toInt();

  // Convert to 12 hour format
  bool isPM = false;
  if (hours == 0) hours = 12;
  else if (hours == 12) isPM = true;
  else if (hours > 12) {
    hours -= 12;
    isPM = true;
  }

  char timeStr[12];
  snprintf(timeStr, sizeof(timeStr), "%02d:%02d %s",
           hours, minutes, isPM ? "PM" : "AM");

  char dateStr[16];
  snprintf(dateStr, sizeof(dateStr), "%02d/%02d/%04d",
           day, month, year);

  String batStr = getBatteryVoltage();

  // Draw to e paper
  display.firstPage();
  do {
    display.fillScreen(GxEPD_WHITE);
    display.setTextColor(GxEPD_BLACK);

    display.setFont(&FreeMonoBold18pt7b);
    display.setCursor(40, 60);
    display.print(timeStr);

    display.setFont(&FreeMonoBold9pt7b);
    display.setCursor(40, 100);
    display.print(dateStr);

    display.setCursor(180, 100);
    display.print(batStr);

  } while (display.nextPage());

  Serial.println("[OK] Display updated");
}

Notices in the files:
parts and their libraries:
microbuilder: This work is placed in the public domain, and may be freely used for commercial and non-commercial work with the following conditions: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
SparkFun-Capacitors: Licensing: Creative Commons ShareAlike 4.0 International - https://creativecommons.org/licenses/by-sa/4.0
